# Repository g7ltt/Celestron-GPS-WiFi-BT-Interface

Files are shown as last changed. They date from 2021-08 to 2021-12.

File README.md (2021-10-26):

# Celestron GPS, WiFi & Bluetooth Interface

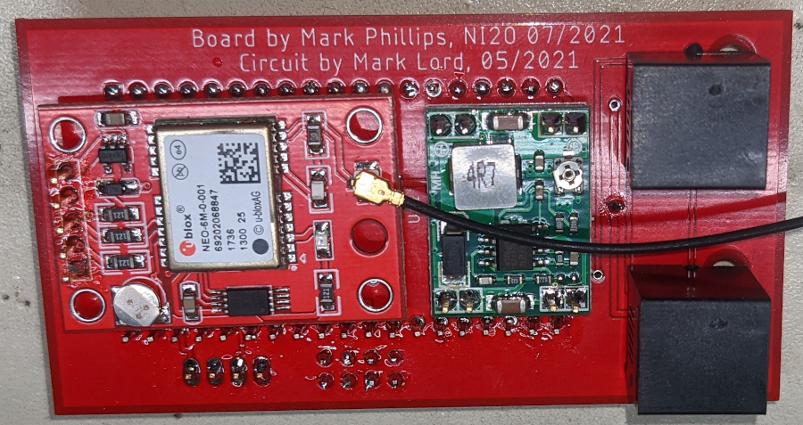
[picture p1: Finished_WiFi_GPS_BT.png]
finished board


My take on Mark Lord's GPS/WiFi/BT interface for Celestron telescope mounts http://rtr.ca/esp32_wifi+bt+gps/

All code is credit to Mark Lord mlord@pobox.com

"For profit" production of this board is expressly forbidden.

Board/schematic files are made with Eagle 9.x.x. PDF file of schematic contains BOM.

Some folks have noted that the ESP32-DevBoard-C as used in this project comes in 2 widths. The V2.0 board now accounts for both widths.

Make sure that you set the voltage from the power PCB to 5.02V BEFORE you add any other PCB's. Failure to set the correct output voltage may result in undesired results and even cause failures of the other parts. Refilling the blue smoke let out by the other components is very nearly impossible for the electronics hobbyist.

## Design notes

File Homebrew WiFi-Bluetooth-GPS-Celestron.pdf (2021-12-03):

# Construction Notes for Homebrew WiFi/Bluetooth/GPS accessory for Celestron telescope mounts

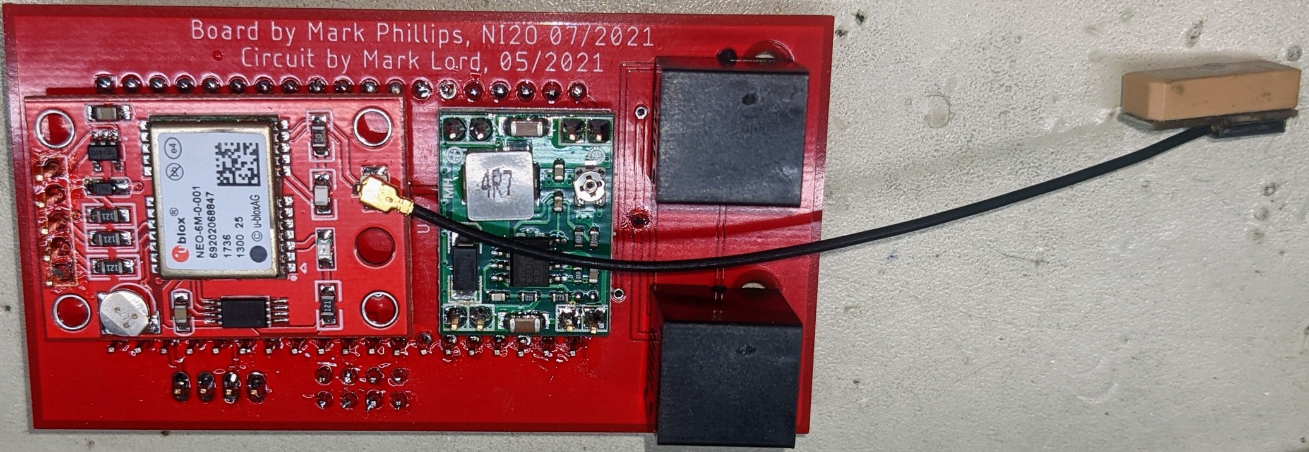
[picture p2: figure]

Circuit and firmware by Mark Lord.
Printed Circuit Board by Mark Phillips, NI2O

Version 1.01
Name | Date | Comments
Mark Phillips | 07/072021 | Initial document creation
Mark Phillips | 10/07/2021 | Publication

### 1.0 Abstract

Celestron telescope mounts supporting the NexStar+ hand controller protocol have various capabilities not included with the initial purchase. These features are available as additional hardware purchases and include such things as GPS time and location sensing, WiFi mount control, Serial computer interface etc.

It is the aim of this project to create a single home made accessory that will enable Celestron mount owners to enable these additional features at a reasonable cost.

### 2.0 Solution

Using the ESP32 microprocessor allows us to not only communicate with the Mount but also bridge other accessories onto the Mount. Commonly available development boards are available that not only contain the microprocessor but also WiFi and Bluetooth antennas. These boards are similar on concept to the Arduino in that they are a carrier board with all of the ESP32 control lines brought out to the edge of a PCB.

The addition of a GPS receiver board, switch mode power supply board, OLED display board and possibly Ethernet boards are possible. No modifications to the mount are required. The accessory plugs directly into the Hand Controller port on the mount thus preserving manufacturers warranties etc.

The use of Common-Off-The-Shelf (COTS) components will greatly reduce both the cost and also the construction skills required for this project. The firmware (software that runs inside the microprocessor) is available for your own modification.

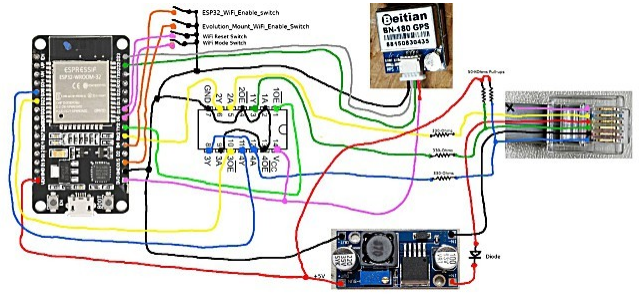
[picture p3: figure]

### 3.0 Construction

### 3.1 Acquiring required components

The latest information on this project can be found at the Cloudy Nights amateur astronomy website here https://www.cloudynights.com/topic/743750-homebrew-wifibluetooth-accessory-for-aux-bus/

### 3.1.1 Bill of Materials (BOM)

You will require the following components to complete this project;

Printed Circuit Board https://github.com/g7ltt/Celestron-GPS-WiFi-BT-Interface Firmware http://rtr.ca/esp32_wifi+bt+gps/
“Red” NEO6M GPS receiver board (check ebay and Amazon)
ESP32S Development Board “C” (Amazon/ebay etc)
MPT1584 Buck Converter DC-DC power supply (Amazon/ebay etc) 4 off 10K 0805 SMD resistors (Amazon/ebay etc)
3 off 330R 0805 SMD resistors (Amazon/ebay etc)
74HC125PW TSSOP Quad line driver (Amazon/ebay etc)
4 pin header (Amazon/ebay etc)
5 pin header (Amazon/ebay etc)
“4x2” pin header and jumpers (Amazon/ebay etc)
4 off 2 pin header (Amazon/ebay etc)
2 off RJ11 6P6C PCB mounted sockets (Amazon/ebay etc)
RJ11 6P6C male-male extension cable (straight - not rolled!!) (Amazon/ebay etc)

Optional components;

0.96” OLED display module
Enclosure
Switches, LED lights

### 3.2 Assembly

### 3.2.1 SMD and headers

On a clean work surface install the Surface Mount Devices (SMD) onto the reverse side of the PCB. Also install the 4 2 pin headers and the 5 pin header as below.

Elsewhere on your bench connect the MPT1584 DC-DC buck converter input to a 12 volt power supply (you can MacGyver a feed from your mount if you don’t have 12V available). Connect a DVM volt meter to the output and set it to measure a 5 volt range. Power on the converter. Insert a small flat blade screwdriver into the screw on the converter and adjust the output voltage to between 4.8 and 5.2 volts.

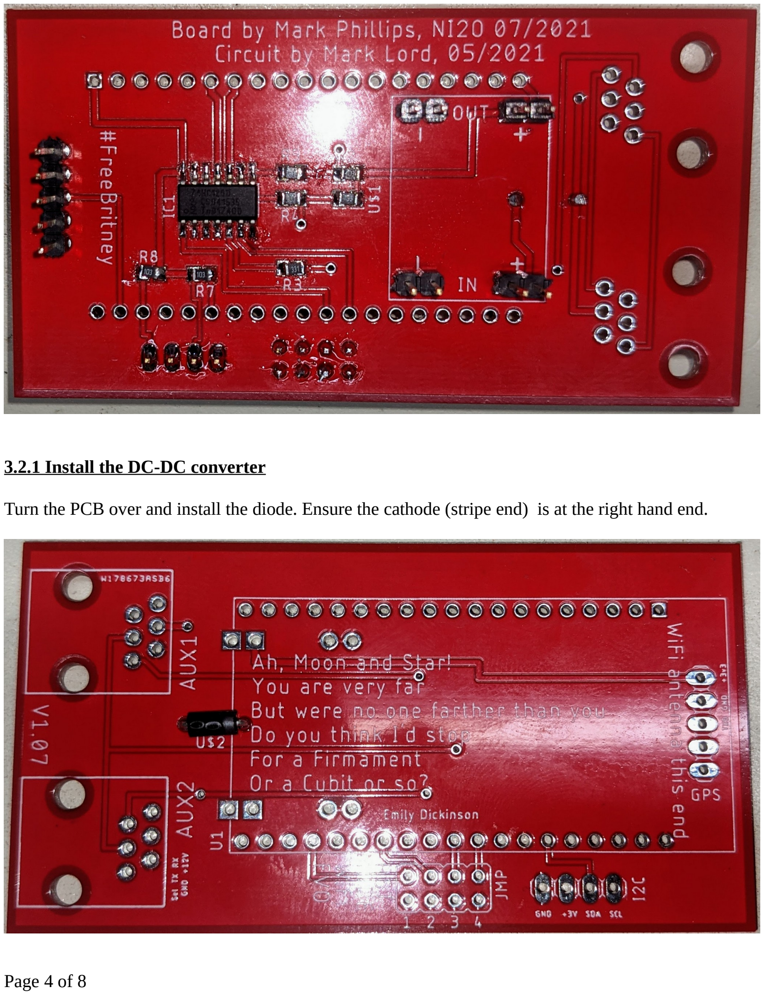
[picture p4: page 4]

### 3.2.1 Install the DC-DC converter

Turn the PCB over and install the diode. Ensure the cathode (stripe end) is at the right hand end.

Turn the board over again and install the DC-DC converter. Refer to the picture below for the correct orientation. The DC-DC board mounts onto the 4 2 pin headers.

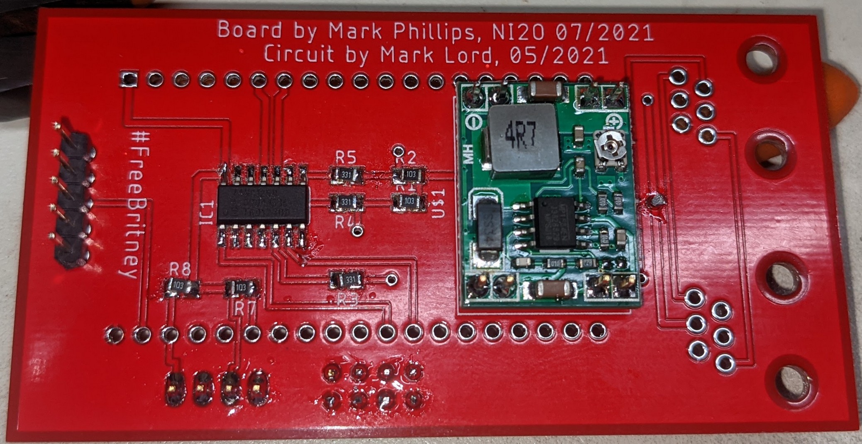
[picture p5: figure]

### 3.2.2 Install the ESP32 microprocessor

Turn the board over again and install the 4x2 pin header/jumpers and the 4 pin header.

Install the ESP32 microprocessor board. Ensure that the WiFi antenna points to the right of the PCB.

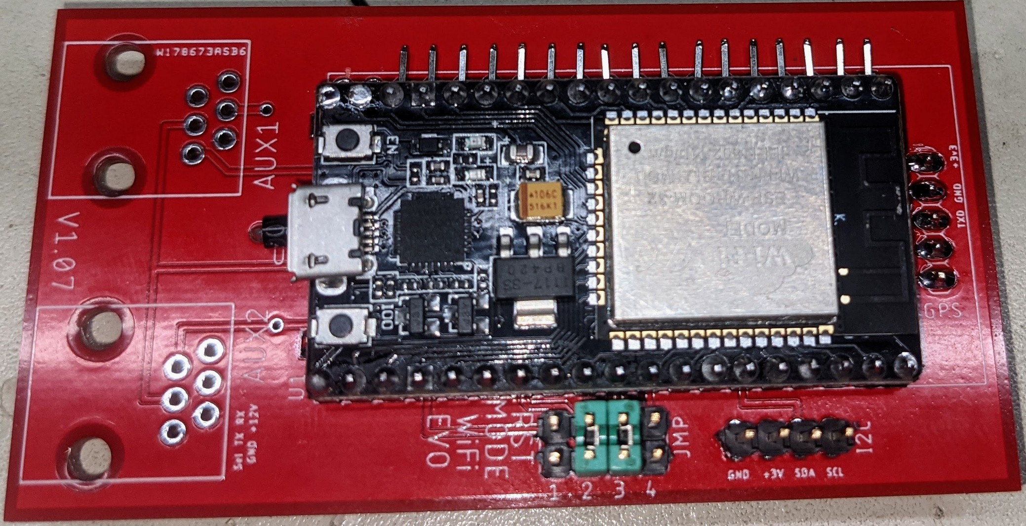
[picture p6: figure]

### 3.2.3 Install the RJ11 connectors

Install the RJ11 sockets on the end of the board. Ensure the hole in the socket faces away from the board.

### 4.0 Install the Firmware

### 4.1 Install/Configure Arduino IDE

It is without the scope of this document to teach the reader how to install and configure their computer with the Arduino IDE software. In addition to the software builders should also install the ESP32 extensions so as to allow for the project firmware to be uploaded to the microprocessor.

The latest Firmware can be found here http://rtr.ca/esp32_wifi+bt+gps/esp32_wifi.ino and in turn contains instructions to aid in the setting of the Arduino IDE and uploading.

### 5.0 Testing

### 5.1 Test accessory with your telescope mount

Deploy your mount outside and connect it up to a well regulated power supply (internal batteries have a tendency to fail quickly). Do not connect the hand controller or turn the mount on yet.

### 5.1.1 Test the Hand Controller

Connect the accessory into the Hand Controller port on your mount. Ensure to position the antenna upwards.
Connect the Hand Controller to the remaining port on the accessory.
Turn on your mount. With a little luck your hand controller will spring to life. Check that its functions are all OK. Do not set the date/time or location.

### 5.1.2 Test the GPS

Wait a few minutes until the LED on the GPS board flashes once per second (signals GPS acquisition). Now change the Hand Controller settings to look for a GPS receiver. Check that the time/date and location have been set by the GPS.

### 5.1.3 Test the WiFi

Using the Celestron SkyPortal app on your cellphone, look for and connect to the WiFi signal being sent out from the accessory. Once connected steer the mount to any location via the app. If you have your telescope loaded onto your mount, try an alignment via the app. Note that the WiFi service presented by the accessory is NOT connected to the Internet.

### 5.1.4 Test the Bluetooth

This part requires that you are using a laptop of some sort (Win/Mac/Linux are all supported). Using your Bluetooth browser on the laptop locate and connect to the Bluetooth signal being sent out from the accessory. Create a serial or comm port from the new Bluetooth device found by your laptop. Using your favorite telescope software such as Celestron’s CPWI, configure it to use the new Bluetooth serial port and then drive the mount to any position.

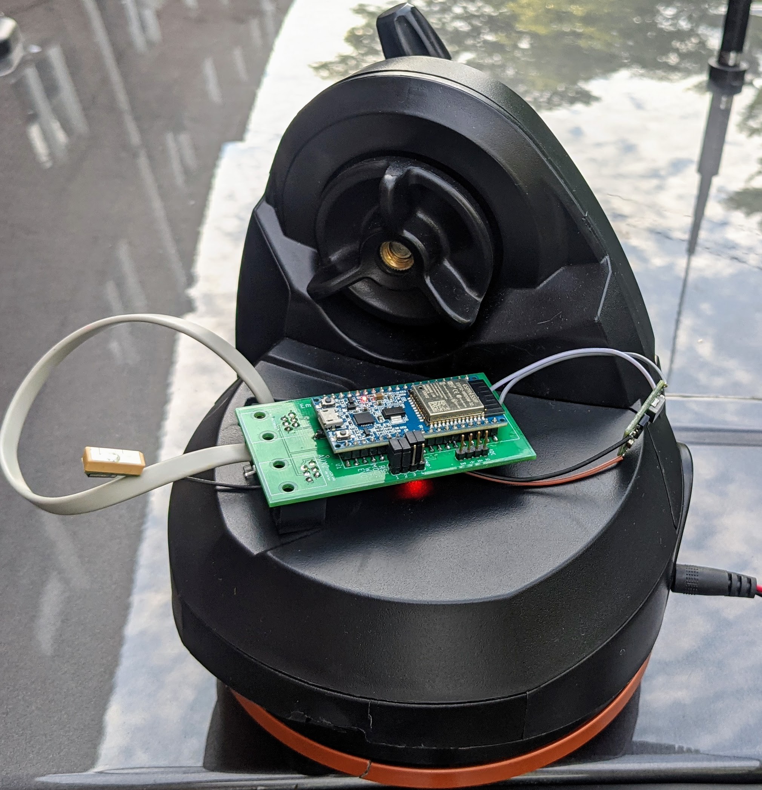
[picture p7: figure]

Prototype Accessory board under test using an old LCM mount

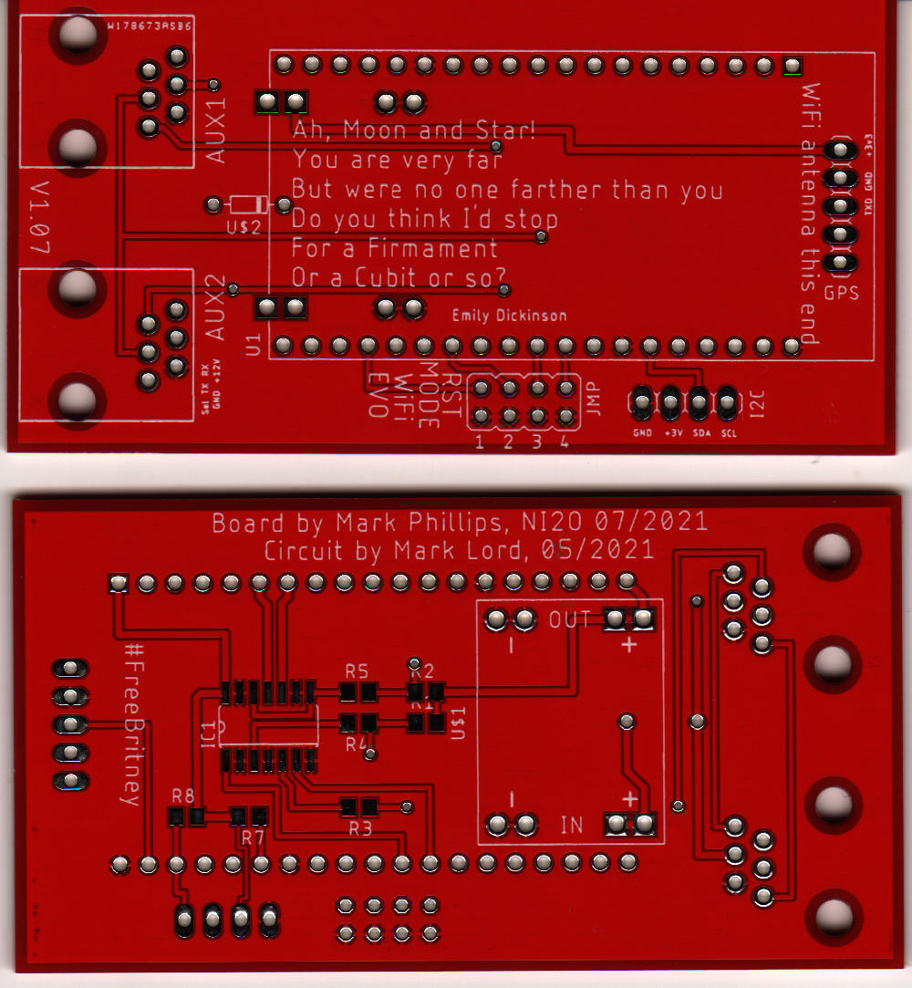
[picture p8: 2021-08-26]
New Blank Boards V1.07.jpg

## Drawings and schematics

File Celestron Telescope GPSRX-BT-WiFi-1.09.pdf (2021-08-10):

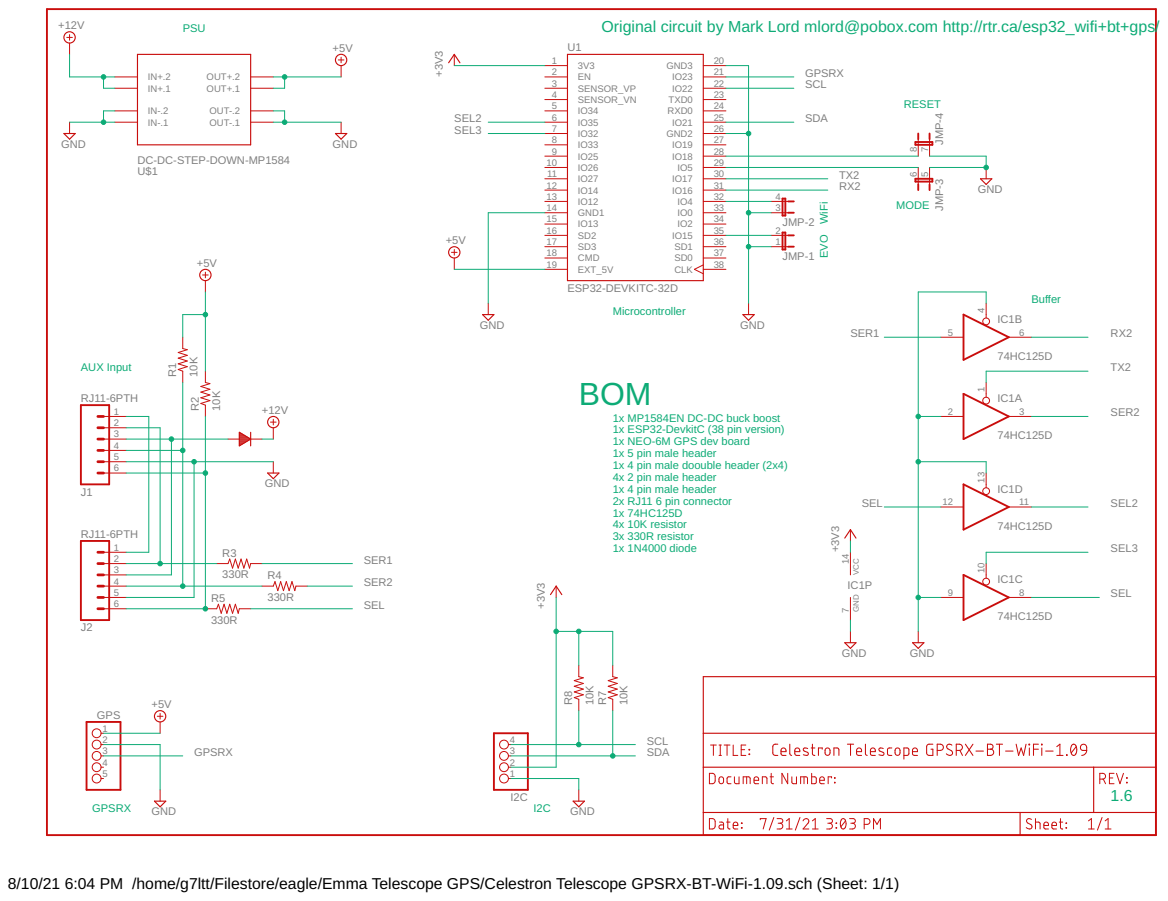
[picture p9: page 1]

Original circuit by Mark Lord mlord@pobox.com http://rtr.ca/esp32_wifi+bt+gps/

DC-DC-STEP-DOWN-MP1584

1x MP1584EN DC-DC buck boost
1x ESP32-DevkitC (38 pin version)
1x NEO-6M GPS dev board
1x 5 pin male header 1x 4 pin male doouble header (2x4)
4x 2 pin male header 1x 4 pin male header 2x RJ11 6 pin connector 1x 74HC125D

8/10/21 6:04 PM /home/g7ltt/Filestore/eagle/Emma Telescope GPS/Celestron Telescope GPSRX-BT-WiFi-1.09.sch (Sheet: 1/1)

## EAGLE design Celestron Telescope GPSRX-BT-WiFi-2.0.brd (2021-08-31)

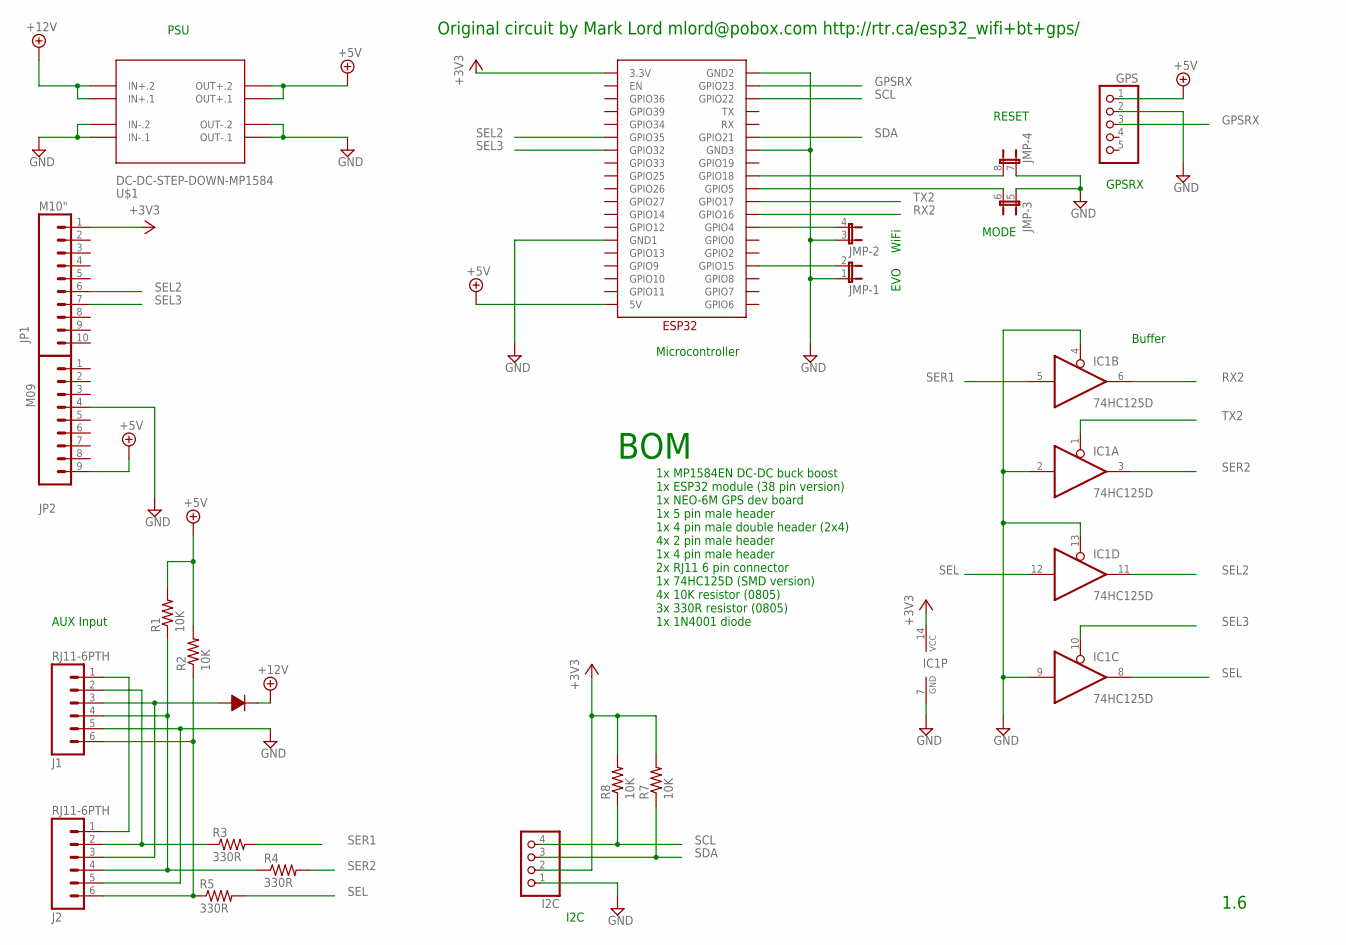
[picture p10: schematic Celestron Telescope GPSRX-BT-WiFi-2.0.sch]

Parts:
GPS: PINHD-1X5; 1X05
I2C: PINHD-1X4; 1X04
IC1: 74HC125D; SO14
J1, J2: RJ11-6PTH; RJ11-6
JMP: JP4QE; JP4Q
JP1: M10"; 1X10
JP2: M09; 1X09
R1, R2, R7, R8: 10K; M0805
R3, R4, R5: 330R; M0805
U$1: DC-DC-STEP-DOWN-MP1584
U$2: 1N4001; DIODE-12.70
U$3: ESP32

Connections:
+3V3: I2C.2, IC1.14 (VCC), JP1.1, R7.2, R8.2, U$3.3.3V
+5V: GPS.1, JP2.9, R1.2, R2.2, U$1.OUT+.1, U$1.OUT+.2, U$3.5V
+12V: U$1.IN+.1, U$1.IN+.2, U$2.P$2
EVO: JMP.2, U$3.GPIO15
GND: GPS.2, I2C.1, IC1.2 (I), IC1.4 (OE), IC1.7 (GND), IC1.9 (I), IC1.13 (OE), J1.5, J2.5, JMP.1, JMP.3 (1), JMP.5 (1), JMP.7 (1), JP2.4, U$1.IN-.1, U$1.IN-.2, U$1.OUT-.1, U$1.OUT-.2, U$3.GND1, U$3.GND2, U$3.GND3
GPSRX: GPS.3, U$3.GPIO23
unnamed: J1.6, J2.6, R2.1, R5.1
unnamed: J1.3, J2.3, U$2.P$1
unnamed: J1.4, J2.4, R1.1, R4.1
unnamed: J1.2, J2.2, R3.1
unnamed: J1.1, J2.1
unnamed: JMP.4 (2), U$3.GPIO4
unnamed: JMP.6 (2), U$3.GPIO5
unnamed: JMP.8 (2), U$3.GPIO18
RX2: IC1.6 (O), U$3.GPIO16
SCL: I2C.4, R8.1, U$3.GPIO22
SDA: I2C.3, R7.1, U$3.GPIO21
SEL: IC1.8 (O), IC1.12 (I), R5.2
SEL2: IC1.11 (O), JP1.6, U$3.GPIO35
SEL3: IC1.10 (OE), JP1.7, U$3.GPIO32
SER1: IC1.5 (I), R3.2
SER2: IC1.3 (O), R4.2
TX2: IC1.1 (OE), U$3.GPIO17

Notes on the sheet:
Original circuit by Mark Lord mlord@pobox.com http://rtr.ca/esp32_wifi+bt+gps/
GPSRX
AUX Input
Microcontroller
PSU
Buffer
EVO
WiFi
RESET
MODE
1.6
I2C
BOM
1x MP1584EN DC-DC buck boost 1x ESP32 module (38 pin version) 1x NEO-6M GPS dev board 1x 5 pin male header 1x 4 pin male double header (2x4) 4x 2 pin male header 1x 4 pin male header 2x RJ11 6 pin connector 1x 74HC125D (SMD version) 4x 10K resistor (0805) 3x 330R resistor (0805) 1x 1N4001 diode

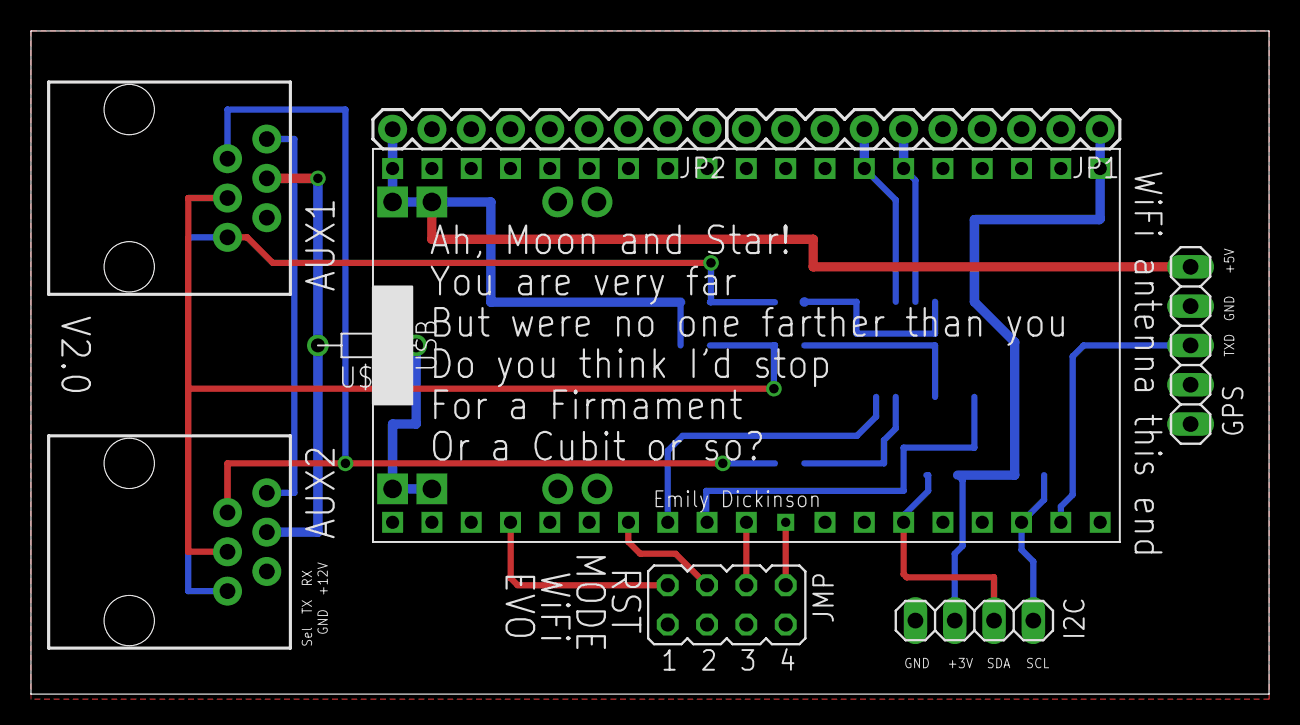
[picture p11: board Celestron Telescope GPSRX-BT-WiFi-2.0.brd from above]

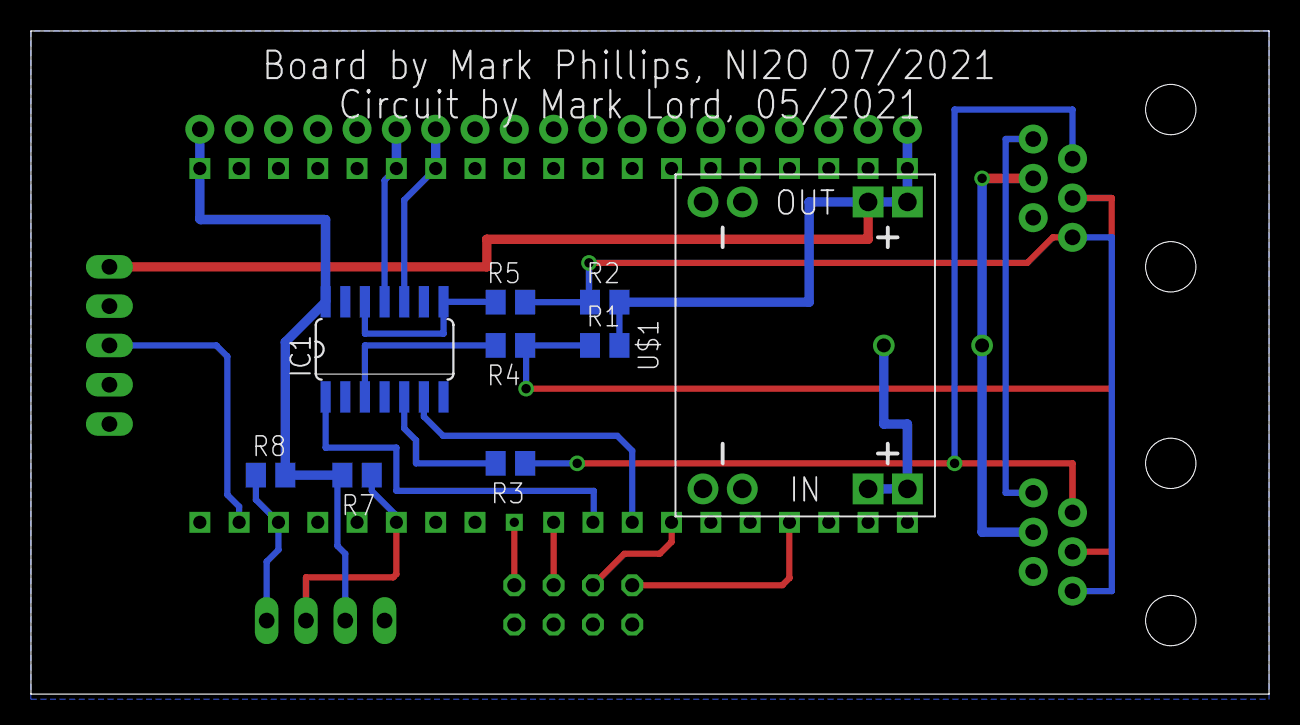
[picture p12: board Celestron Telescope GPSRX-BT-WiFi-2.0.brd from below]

Board: 2 copper layers, 80.0 x 42.9 mm, 18 parts (9 on the bottom side), 23 nets.

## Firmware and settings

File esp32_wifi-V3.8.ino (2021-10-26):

/*
 * ESP32 Home-Brew GPS+WiFi+BT for the Celestron Nexstar AUX bus.
 * Copyright(c) Mark Lord <mlord@pobox.com>.
 * This code is free for personal use/modification/whatever.
 */
#define VERSION "3.8"
#define VERSION_DATE "2021-10-18"
/*
 * Arduino IDE configuration for this project:
 *  -- Remove all use of LED_PIN, in preparation for using SPI bus.
 *  -- First, select Board="ESP32 Dev Module".
 *  -- Now choose Partition Scheme="Huge APP (3MB..)".
 *  -- and also CPU Frequency = 80Mhz (WiFi/BT).
 *
 * Version 3.8
 *  -- Add 'exit' command for port 3000.
 *  -- Fix Bluetooth:  replace BT_AUX_ENABLED with BT_ENABLED.
 * Version 3.7
 *  -- Receive/discard echos of packets we send to auxbus, instead of trying auxbus.flush().
 *  -- NexstarGPS: emulate responses for MC_GET_MAX_RATE, MC_GET_MAX_SLEW_RATE command from CPWI.
 * Version 3.6
 *  -- Fix false detection of non-existing GPS receivers.
 *  -- Add 'g' command to toggle GPS debugging
 * Version 3.5
 *  -- Reinstate 15-second connection timeout for recovery from wifi drops.
 *  -- Added automatic management of EVO WiFi as alternative to having a switch for it.
 *  -- More code refactoring to enable use of W5500 ethernet eventually.
 *  -- For Nexstar-GPS mounts, emulate a CPC mount instead.
 *  -- New pin assignments going forward, to eliminate conflicts with SPI/I2C.
 * Version 3.4
 *  -- Doh. Fix bug in GPS-8 compatibility code.
 *  -- Fix corner cases for the new buffering.
 * Version 3.3
 *  -- Implemented buffering of non-0x3b pkt data bytes for WiFi/BT transmission.
 *  -- Fixed harmless (?) bug with Starsense 0x3c data handling.
 *  -- Work on compatibility for older mounts such as the GPS-8.
 * Version 3.2
 *  -- Fix BT SSID generation, and tidy up WiFi mac access/use everywhere.
 * Version 3.1
 *  -- Revamp w2000/w3000 handling using globals for WiFiClient objects.
 *  -- Get rid of auxbus_over_usbserial: nobody wants/uses it.
 *  -- Lots of code revamping/tidying.
 * Version 3.0
 *  -- Remove StarSense Simulator: no longer needed.
 *  -- use "#if BT_ENABLED" instead of "if (BT_ENABLED)"
 * Version 2.9
 *  -- Code cleanups and some restructuring.
 * Version 2.8
 *  -- Add a hyphen into the BT_ID.
 *  -- Add StarSense Camera Simulator
 *  -- Apply various fixes to make WiFi+BT work with StarSense Camera
 * Version 2.7
 *  -- Enable Bluetooth (BT) by default: it works(!) with CPWI.
 *  -- Generate unique BT id based on WiFi hardware mac address.
 * Version 2.6
 *  -- Update auxbus_receive() to better handle StarSense Camera 0x3c packets.
 * Version 2.5
 *  -- Allow for arbitrary auxbus protocols and arbitrary auxbus message sizes.
 * Version 2.4
 *  -- Allow for auxbus messages with up to the protocol limit of 256 bytes payload
 *  -- Get rid of unnecessary rxbuf->count field.
 * Version 2.3
 *  -- Fix GPS pin confusion and add an explanation.
 * Version 2.2
 *  -- Move VERSION to the end of the ADAPTER_VERSION string.  Print it at startup.
 *  -- Change BUSYOUT-to-tx delay to 100 microseconds.
 *  -- Get rid of the verbose=0/1 messages.
 * Version 2.1c
 *  -- New usbserial commands: 't' send test msg; 'v' toggle verbose.
 *  -- Add BUSY diagnostics when verbose=1.
 *  -- Increase BUSYOUT-to-tx delay to 500 microseconds.
 * Version 2.1
 *  -- Fix LED so that it is only on when there's a WiFi connection.
 *  -- Fix parser error on w3000.
 * Version 2.0
 *  -- Get rid of w2000 timeouts: don't seem to be needed after all.
 *  -- Disable Bluetooth by default.
 *  -- Prepend millisecond timestamps to print_packet() output.
 *  -- Replace BUILD_BT flag with BT_ENABLED flag
 *  -- Fixed code use VERBOSE again.
 *  -- Tidying.
 * Version 1.9
 *  -- Make changes to the WiFi mode immediate, both from vars and the physical switch.
 *  -- In the event that the Client parameters are incomplete, it will revert to SoftAP
 *      mode until new vars are "saved".
 * Version 1.8
 *  -- Implemented auxbus_over_usbserial.  Pull pin-19 LOW at startup to activate it.
 *      In theory, this allows for use of MCupdate over the USB-Serial connection.
 *  -- Remap hardware-serial-0 to the GPS, and hardware-serial-1 to USB.
 *      This gets rid of spurious debug messages from Arduino libraries that might mess up auxbus_over_usbserial.
 *  -- Reset the w2000_rxbuf on new connection.
 *  -- Added a (disabled) "version" command on port 3000, same as Celestron.  Enables CFM to detect us.
 * Version 1.7
 *  -- Try to arrange wifi code more sensibly.
 *  -- Added a "verbose" variable on port 3000.
 *  -- Use a (likely) unique default SSID which includes the final 6-digits of MAC.
 *  -- Corrected Pin-D5 to Pin-5 everywhere.
 *  -- Added wifi "reset" command on port 3000.
 *  -- Tidying.
 * Version 1.6
 *  -- Implemented port 3000 management interface.
 *  -- Implemented get/set for all variables used by SkyPortal.
 *  -- Save/restore variables in flash memory.
 *  -- Implemented WiFi-client mode, using config from wlan variables.
 *  -- Designated Pin-18 for use as "restore defaults" in case of misconfiguration.
 *  -- Designated Pin-5 for WiFi mode switch.
 *  -- Added a variable for "wifi.mode": 0=SoftAP, 1=Client, anything else uses the Pin-5 switch.
 *  -- Don't report GPS capability until after a GPSr is detected on its serial port.
 * Version 1.5
 *  -- Reconfigured the board definition to use "huge_app" partitions layout.
 *  -- General tidying.
 * Version 1.4
 *  -- Added working BlueTooth serial support!
 *  -- Not enough flash memory on the ESP32 to hold everything at once though.
 *  -- Need to select BUILD_* features at compile time now.
 * Version 1.3 
 *  -- SkyPortal app now connects instantly! 
 *  -- Added UDP advertisement broadcasts.
 *  -- Added NULL responses to timed-out "GET_VER" queries.
 *  -- Added TCP KEEPALIVE packets at 2000msec intervals.
 * Version 1.2
 *  -- General tidying.
 *  -- Added WiFi on/off switch for ESP32 wifi, using GPIO15 pin.
 *  -- Added WiFi on/off switch for internal EVO wifi, using GPIO4/D4 pin.
 * Version 1.1
 * Version 1.0
 *  -- Initial release.
 *       GPS+WiFi are both working well. Bluetooth (BT) not yet implemented.
 *  -- SkyPortal has a longish delay at startup with the WiFi (be patient).
 *       This is mainly due to SkyPortal polling for StarSense and Focuser.
 *       The Celestron Wifi responds after 100msec with an empty TCP packet,
 *       and I have yet to figure out how to get the ESP32 to do the same.
 *  -- Shorter TCP timeouts not yet implemented; might not be necessary.
 *  -- Wiring schematic not yet drawn up, but circuit uses a 74HC125 for interfacing.
 *
 * The onboard Blue LED is lit when SkyPortal is connected and communicating.
 * It turns off (normally very briefly) when SkyPortal is waiting for a response,
 * or when SkyPortal is no longer connected.
 */

#define VERBOSE           false   // Can also be toggled at run-time (hit 'v' on serial monitor)
#define BT_ENABLED        true    // When false, Bluetooth code is completely left out
#define ETH_ENABLED       false   // When false, Ethernet code is completely left out
#define USE_ORIGINAL_PINS true    // When true, use original pin assignments; when false, use improved pin assignments

static bool verbose;
static bool gpsverbose =  false;  // Can be toggled at run-time (hit 'g' on serial monitor)

#define DEFAULT_SSID       "HomeBrew"
#define ADAPTER_VERSION    DEFAULT_SSID "-AMW007-9.0.0.0, " VERSION_DATE "T12:00:00Z, ESP32-" VERSION
// Celestron reports: "ZENTRI-AMW007-1.2.0.10, 2017-07-28T07:43:27Z, ZentriOS-WL-1.2.0.10, Board:N/A");

#define AUXBUS_TXQ_SIZE     8
#define AUXBUS_PKT_MAX     32    // Max length of a regular 0x3b style auxbus packet

#include <WiFi.h>
#include <lwip/sockets.h>
#include <WiFiClient.h>
#include <WiFiAP.h>
#include "AsyncUDP.h"
#include "FS.h"
#include "SPIFFS.h"
#include <TinyGPS++.h>

// PIN definitions for this project:
#define AUXBUS_RX_PIN               16  // Serial port 2 RX pin
#define AUXBUS_BUSYOUT_PIN          32  // The RTS (aka. "Busy") line output to Nexstar auxBus
#define AUXBUS_BUSYIN_PIN           35  // The RTS (aka. "Busy") line input from Nexstar auxBus
#define GPS_TX_PIN                  22  // TX-to-GPS pin. Possibly wired to the GPS RX pin, but we never send anything (CONFLICT with I2C SCL)

// Some of the original PIN choices conflict with SPI and I2C busses.
// The default I2C wants pins 21(SDA), 22(SCL).
// The default SPI wants pins 18(SCK), 19(MISO), 23(MOSI), and SS pins: 5(USBhost), 10(ethernet).

// Keep the original PINs for existing units, but redefine them for going forward.
#if USE_ORIGINAL_PINS
#define AUXBUS_TX_PIN               17  // TX2.  All-in-one uses 17 for USBHost-INT, and uses 4(D4) here instead.
#define EVO_WIFI_OFF_PIN            15  // Internal WiFi: ground to turn on, float high to turn off; undefine for automatic on/off.
#define ESP32_WIFI_OFF_PIN           4  // ESP32 WiFi: ground to turn on, float high to turn off
#define ESP32_WIFI_MODE_PIN          5  // ESP32 WiFi: ground to select client-mode; float high for SoftAP mode (CONFLICT with SPI SS)
#define ESP32_RESTORE_DEFAULTS_PIN  18  // ESP32 WiFi: ground to restore vars defaults at wifi startup (CONFLICT with SPI SCK)
#define GPS_RX_PIN                  23  // RX-from-GPS pin.  GPS's TX pin (white) gets connected here (CONFLICT with SPI MOSI)
#else
#warning "Using modified PIN assignments; will NOT work with existing pre-wired projects!!"
#define AUXBUS_TX_PIN                4  // was 17(TX2) but conflicts with USBHost INT pin
#define ESP32_WIFI_OFF_PIN          39  // ESP32 WiFi: ground to turn on, float high to turn off
#define ESP32_WIFI_MODE_PIN         34  // ESP32 WiFi: ground to select client-mode; float high for SoftAP mode
#define GPS_RX_PIN                  33  // RX-from-GPS pin.  GPS's TX pin (white) gets connected here
#endif

HardwareSerial gpsr(1);      // Hardware serial port 1
HardwareSerial auxBus(2);    // Hardware serial port 2, used for Celestron AUX bus

#define LED_ON               HIGH
#define LED_OFF              LOW

static uint8_t    wifi_mac_addr[6];  // Filled in by setup(), used to create unique SSIDs
static WiFiClient w2000;      // The wifi application port 3000, for controlling the mount
static WiFiClient w3000;      // The wifi management  port 3000, for configuring the adapter

// Various "known" device IDs on Nexstar auxBus:
#define DEV_MAIN            0x01
#define DEV_HC              0x04
#define DEV_HC_PLUS         0x0d
#define DEV_HC_SS           0x0e  /* StarSense Hand Controller */
#define DEV_AZM_MC          0x10
#define DEV_ALT_MC          0x11
#define DEV_FOCUSER         0x12
#define DEV_SKYPORTAL       0x20  /* SkyPortal app */
#define DEV_GPS             0xb0  /* Celestron or homebrew GPS */
#define DEV_SP_WIFI         0xb3  /* SkyPortal Wifi */
#define DEV_SSCAMERA        0xb4  /* StarSense Camera */
#define DEV_EVO_WIFI        0xb5  /* EVO Wifi Device */
#define DEV_BATTERY_PC      0xb6  /* EVO Battery Controller */
#define DEV_CHARGE_PORT     0xb7  /* EVO Charge Port */
#define DEV_MOUNT_LIGHTS    0xbf  /* EVO Mount/Tray Lights */
#define DEV_ESP32           0xe2  /* This ESP32 board */
#define DEV_DUMMY           0xe3  /* dummy address when switching evo wifi on/off */

// get a non-zero timeout:
static inline long get_timeout(unsigned int t)
{
   long m = millis() + t;
   return m ? m : 1;
}

// Compare against current time, handling wraparound:
static inline bool time_after (long a, long b)
{
  return (b - a) < 0;
}
#define time_before(a,b) time_after((b),(a))

static struct rxbuf_s {
  byte len;
  byte csum;
  byte data[AUXBUS_PKT_MAX];
  byte requestor;
  const char *name;
} w2000_rxbuf, auxbus_rxbuf;

#if ETH_ENABLED
static struct rxbuf_s e2000_rxbuf;
static void e2000_tx (byte *data, uint16_t len);
#endif

static bool         esp32_wifi_off = true;
static AsyncUDP     udp;
static char         advertisement[128];
static WiFiServer   W2000(2000);  /* Listen on port 2000 for SkyPortal connections */
static WiFiServer   W3000(3000);  /* Listen on port 3000 management commands */

// Because this module implements multiple devices (GPS+BT+Wifi),
//  it is possible that more than one packet may need to be sent simultaneously
//  over the auxbus.  And the bus itself could be in-use from another device at
//  any point in time.  So outbound packets get queued up here and sent when the
//  bus is available.
struct pkt_s {
  uint16_t len;
  byte     data[AUXBUS_PKT_MAX];
};
static struct pkt_s auxbus_txq[AUXBUS_TXQ_SIZE];
static byte         auxbus_txq_head = 0;  // next slot for adding to queue
static byte         auxbus_txq_tail = 0;  // next slot to take from

static void print_packet (const char *prefix, byte *data, uint16_t len)
{
  Serial.printf("%09lu %s: ", millis(), prefix);
  for (uint16_t i = 0; i < len; ++i)
    Serial.printf("%02x ", data[i]);
  Serial.println("");
}

static void auxbus_tx_enq (bool raw, const byte *buf, uint16_t len)
{
  struct pkt_s *p = &auxbus_txq[auxbus_txq_head];
  byte *data = p->data;
  if (p->len != 0) {
    Serial.println("auxbus tx overflow");
    return;
  }
  if (raw) {
    if (len > sizeof(p->data)) {
      Serial.println("auxbus_tx too large");
      return;
    }
    // Copy raw buf to txq, as-is.
    p->len = len;
    memcpy(data, buf, len);
  } else {
    // Prefix with 0x3b, copy buf to txq, and calculate/append the checksum.
    byte csum = len;
    *data++ = 0x3b;
    *data++ = len;
    while (len--) {
      byte c = *buf++;
      csum  += c;
      *data++ = c;
    }
    *data++ = -csum;
    p->len = data - p->data;
  }
  if (++auxbus_txq_head >= AUXBUS_TXQ_SIZE)
    auxbus_txq_head = 0;
}

static TinyGPSPlus gps;
static bool        gpsr_detected = false;  /* Don't respond as DEV_GPS unless a GPSr is detected */

// GPS related commands over Nexstar auxBus:
#define GPS_GET_LAT         0x01
#define GPS_GET_LONG        0x02
#define GPS_GET_DATE        0x03
#define GPS_GET_YEAR        0x04
#define GPS_GET_SAT_INFO    0x07
#define GPS_GET_RCVR_STATUS 0x08
#define GPS_GET_TIME        0x33
#define GPS_TIME_VALID      0x36
#define GPS_LINKED          0x37
#define GPS_GET_HW_VER      0x55
#define GPS_GET_COMPASS     0xa0
#define DEV_GET_VER         0xfe

#define GPS_HW_VER          0xeb    // home-brew GSPr hardware version, to avoid "mount confusion" in CFM

// Changing these to use GNSS reports.  Should probably make it either/or.
TinyGPSCustom satellitesInView(gps, "GPGSV", 3);
TinyGPSCustom fix3D(gps, "GPGSA", 2);          // 1 = no fix,  2 = 2D fix, 3 = 3D fix
TinyGPSCustom fixQuality(gps, "GPGGA", 6);     // 0 = invalid, 1 = GPS,    2 = DGPS, etc...
TinyGPSCustom fix3DGNSS(gps, "GNGSA", 2);      // 1 = no fix,  2 = 2D fix, 3 = 3D fix
TinyGPSCustom fixQualityGNSS(gps, "GNGGA", 6); // 0 = invalid, 1 = GPS,    2 = DGPS, etc...

// For more details how convert GPS position into 24 bit format,
//  see "NexStar Communication Protocol", section "GPS Commands".
// https://www.nexstarsite.com/download/manuals/NexStarCommunicationProtocolV1.2.zip
static const double GPS_MULT_FACTOR = 46603.37778;  // = 2^24 / 360

// Handle both GNSS and GPS format strings
static int getGpsQuality()
{
  String quality(fixQualityGNSS.value());
  if (quality.length())
    return quality.toInt();
  quality = fixQuality.value();
  if (quality.length())
    return quality.toInt();
  return -1;
}

static void handle_gps_request (byte *buf)
{
  if (!gpsr_detected)
    return;
  byte reply[16], op, len = 3;
  reply[0] = buf[3]; //pdst (DEV_GPS)
  reply[1] = buf[2]; //psrc
  reply[2] = op = buf[4];
  switch (op)
  {
    case GPS_LINKED:
    case GPS_TIME_VALID: {
      byte have_gps_fix = getGpsQuality() > 0;
      reply[len++] = have_gps_fix;
      break;
    }

    case GPS_GET_TIME: {
      reply[len++] = gps.time.hour();
      reply[len++] = gps.time.minute();
      reply[len++] = gps.time.second();
      break;
    }

    case GPS_GET_HW_VER: {
      reply[len++] = GPS_HW_VER;
      break;
    }

    case GPS_GET_YEAR: {
      uint16_t year = gps.date.year();
      reply[len++] = year >> 8;
      reply[len++] = year;
      break;
    }

    case GPS_GET_DATE: {
      reply[len++] = gps.date.month();
      reply[len++] = gps.date.day();
      break;
    }

    case GPS_GET_LAT: {
      int32_t lat = (int32_t) (gps.location.lat() * GPS_MULT_FACTOR);
      uint8_t* latBytePtr = (uint8_t*)&lat;
      reply[len++] = latBytePtr[2];
      reply[len++] = latBytePtr[1];
      reply[len++] = latBytePtr[0];
      break;
    }

    case GPS_GET_LONG: {
      int32_t lng = (int32_t) (gps.location.lng() * GPS_MULT_FACTOR);
      uint8_t* lngBytePtr = (uint8_t*)&lng;
      reply[len++] = lngBytePtr[2];
      reply[len++] = lngBytePtr[1];
      reply[len++] = lngBytePtr[0];
      break;
    }

    case GPS_GET_SAT_INFO: {
      String satellitesInViewString(satellitesInView.value());
      reply[len++] = satellitesInViewString.toInt();
      reply[len++] = gps.satellites.value();
      break;
    }

    case DEV_GET_VER: {
      reply[len++] = 2;  // Version 2.0
      reply[len++] = 0;
      break;
    }

    case GPS_GET_RCVR_STATUS:
    case GPS_GET_COMPASS:
    default:
      return;
  }
  auxbus_tx_enq(false, reply, len);
}

static void init_rxbuf (struct rxbuf_s *buf, const char *name)
{
  memset(buf, 0, sizeof(*buf));
  buf->name = name;
}

enum {pkt_fail, pkt_inprogress, pkt_complete};

static byte last_auxbus_tx[AUXBUS_PKT_MAX] = {0,};
static byte last_auxbus_tx_len = 0;

static inline byte packet_reset (struct rxbuf_s *buf, byte ret)
{
  if (buf == &auxbus_rxbuf)
    last_auxbus_tx_len = 0;
  else
    buf->len = 0;
  return ret;
}

static byte packet_decoder (struct rxbuf_s *buf, byte b)
{
  static uint16_t sscount = 0, sslen = 0;   // Used to crudely track/debug StarSense camera 0x3c packets
  buf->data[buf->len++] = b;
  if (buf->len == 1) {
    if (b != 0x3b) {
      if (verbose)
        Serial.printf("%09u %s: %02x\n", millis(), buf->name, b);
      //buf->len = 0;  /* FIXME: uncomment this for testing with GPS-8 mount */
      if (!sscount) {
        if (b == 0x3c)
          sscount = 1;
      } else {
        if (++sscount == 4)
          sslen = b;
        else if (sscount == 5)
          sslen = ((sslen << 8) | b) + 6;
      }
      return packet_reset(buf, pkt_fail);
    }
    if (sscount)
      Serial.printf("%09u Starsense: %u/%u\n", millis(), sscount, sslen);
    if (sscount == sslen)
      sscount = sslen = 0;
    buf->csum = 0;
    return pkt_inprogress;
  }
  buf->csum += b;
  if (buf->len == 1)
    return pkt_inprogress;
  if (buf->len == 2) {
    if (b < 3 || b >= (sizeof(buf->data) - 5)) {
      if (verbose)
        Serial.printf("%s: bad len %02x\n", buf->name, b);
      return packet_reset(buf, pkt_fail);
    }
    return pkt_inprogress;
  }
  if (buf->len != (buf->data[1] + 3))
    return pkt_inprogress;
  if (buf->csum != 0) {
    if (verbose)
      Serial.printf("%s: bad csum %02x\n", buf->name, buf->csum);
    return packet_reset(buf, pkt_fail);
  }

  // Handle a fully completed packet:
  if (buf->len == last_auxbus_tx_len && buf == &auxbus_rxbuf) {
    if (0 == memcmp(buf->data, last_auxbus_tx, last_auxbus_tx_len)) {
      buf->len = 0;  // echo-back of last auxbus packet we sent: discard it
      return packet_reset(buf, pkt_fail);
    }
  }
  buf->requestor = buf->data[2];
  byte target    = buf->data[3];
  if (verbose || target == DEV_ESP32) {
    if (target == DEV_ESP32)
      Serial.print("Received: ");
    print_packet(buf->name, buf->data, buf->len);
  }
  if (target == DEV_GPS)
    handle_gps_request(buf->data);
  if (buf != &auxbus_rxbuf)
    auxbus_tx_enq(true, buf->data, buf->len);
  return packet_reset(buf, pkt_complete);
}

#if BT_ENABLED
#include "BluetoothSerial.h"
BluetoothSerial        bt;
static struct rxbuf_s  bt_rxbuf;
static bool            bt_connected = false;

static inline void bt_tx (byte *data, uint16_t count)
{
  if (bt_connected) {
    bt.write(data, count);
    if (verbose)
      print_packet(__func__, data, count);
  }
}
#endif /* BT_ENABLED */

static void w2000_tx (byte *data, uint16_t count)
{
  if (!esp32_wifi_off && w2000.connected()) {
    w2000.write(data, count);
    if (verbose)
      print_packet(__func__, data, count);
  }
}

static void insert_checksum (byte *data, uint16_t len)
{
  if (len-- < 6 || data[0] != 0x3b)
    return;
  byte i, csum = data[1];
  for (i = 2; i < len; ++i)
    csum += data[i];
  data[len] = -csum;
}
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
void loop()
{
  manage_evo_wifi_switch();  // Does nothing unless EVO_WIFI_OFF_PIN is defined
  manage_esp32_wifi_onoff();
  service_non_wifi_devices();
  service_w2000();
  service_w3000();
#if ETH_ENABLED
  ethernet_loop();
#endif
}

void setup()
{
  // Get the auxbus configured before _anything_ else:
  pinMode(AUXBUS_BUSYOUT_PIN,      OUTPUT);
  digitalWrite(AUXBUS_BUSYOUT_PIN, HIGH);  // Tri-state BUSYOUT
  pinMode(AUXBUS_BUSYIN_PIN,       INPUT);
  auxBus.begin(19200, SERIAL_8N2, AUXBUS_RX_PIN, AUXBUS_TX_PIN);
  auxBus.setRxBufferSize(900);  // Large enough for SS_CAMERA packets, plus some

#ifdef ESP32_RESTORE_DEFAULTS_PIN
  pinMode(ESP32_RESTORE_DEFAULTS_PIN, INPUT_PULLUP);
#endif
  pinMode(ESP32_WIFI_MODE_PIN, INPUT_PULLUP);
  pinMode(ESP32_WIFI_OFF_PIN,  INPUT_PULLUP);

  Serial.begin(115200, SERIAL_8N1);

  esp_read_mac(wifi_mac_addr, ESP_MAC_WIFI_STA);

  vars_restore();  // this also sets "verbose" appropriately
  init_rxbuf(&auxbus_rxbuf,    "auxbus_rx");
  init_rxbuf(&w2000_rxbuf,     "w2000_rx");

#if BT_ENABLED
  char bt_id[32];
  sprintf(bt_id, "%s-%02X%02X%02X", DEFAULT_SSID, wifi_mac_addr[3], wifi_mac_addr[4], wifi_mac_addr[5]);
  bt.begin(bt_id);
  init_rxbuf(&bt_rxbuf, "bt_rx");
#endif /* BT_ENABLED */

  gpsr.begin(9600, SERIAL_8N1, GPS_RX_PIN, GPS_TX_PIN);
  memset(auxbus_txq, 0, sizeof(auxbus_txq));
  Serial.println(ADAPTER_VERSION);
#if ETH_ENABLED
  ethernet_setup();
#endif
}

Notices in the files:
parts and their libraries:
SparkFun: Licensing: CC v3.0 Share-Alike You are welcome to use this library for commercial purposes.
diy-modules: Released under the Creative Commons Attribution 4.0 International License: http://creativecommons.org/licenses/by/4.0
